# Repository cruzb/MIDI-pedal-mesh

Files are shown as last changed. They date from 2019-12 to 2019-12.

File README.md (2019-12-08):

# MIDI Pedal and Mesh
Digital music production today has a lot of limits. In an analog world a musician can slightly tweak the angle of their bow on a violin to get a different sound. The aim of the “Mesh” is to create a digital instrument with analog levels of control in package compatible with existing digital workflows.

Effects pedals are a common tool used by guitarists to modify the sound of their instrument. These devices are often designed to make one specific sound. The aim of the “Pedal” is to create a customizable audio processing device that gives users direct access to DSP hardware while maintaining the functionality and ease of use that musicians expect.

### Watch this video to see it in action
Watch the video (https://www.youtube.com/watch?v=qIbVKWIkZBc)

## Implementation
### Overview
The Mesh and Pedal work as standard audio components that can fit seamlessly into any musician’s kit. The Mesh outputs a MIDI signal which can be use to generate sound through any MIDI-capable synthesizer. The Pedal takes in analog audio and performs effects processing on it before outputting it to an amplifier or speaker for play. These devices can work in tandem, independently, or with other music devices.

How it Works Together

### Pedal
- Users create effects programs on desktop and upload to the device EEPROM via a desktop application and USB connection
- Once loaded to the pedal programs can be selected via a knob
- An LCD screen in the pedal displays the active program and up to three associated parameters for it
- Input analog audio is split into two independent signal paths and processed by the selected program on an FV-1 DSP chip
- The affected signal then runs through an analog equalizer and is blended with the clean signal before it is output.

### Mesh
- Use strain sensors to read force data on two axes via ADC
- Use ADC data to do basic 2D localization of which point in grid is most pressed and by how much
- Map that point to a pitch, pitch-bend, and velocity for MIDI
- Generate MIDI packets from these data
- Send MIDI via UART at 31250 baud

## PCB Design
Three PCBs were created for this project. One for the pedal and two for the mesh. The pedal PCB contains over 160 components that handle digital and analog signals. The mesh PCBs are simpler but took special design considerations into account. Because of the analog nature of the device all analog runs were made as short as possible and processing occurs close to the sensors to deal with noise issues.

Pedal PCB Image

## Major Compontents
### Pedal
- PIC16F15355 Microcontroller
- FV-1 Spin Semiconductor DSP Chip
- HD44780-Compatible RGB 16x2 Character LCD
- FT232 USB-UART Interface
- 24LC32A External EEPROM Chip
- MAX4910ETE Audio Switch

### Mesh
- PIC16F15376 Microcontroller
- TAL221 Load Cell
- AD620 Differential Amplifier

#### Made with Jordan Frank, Ethan Brown, Charlie Light, and Spencer Haney for University of Michigan EECS 473

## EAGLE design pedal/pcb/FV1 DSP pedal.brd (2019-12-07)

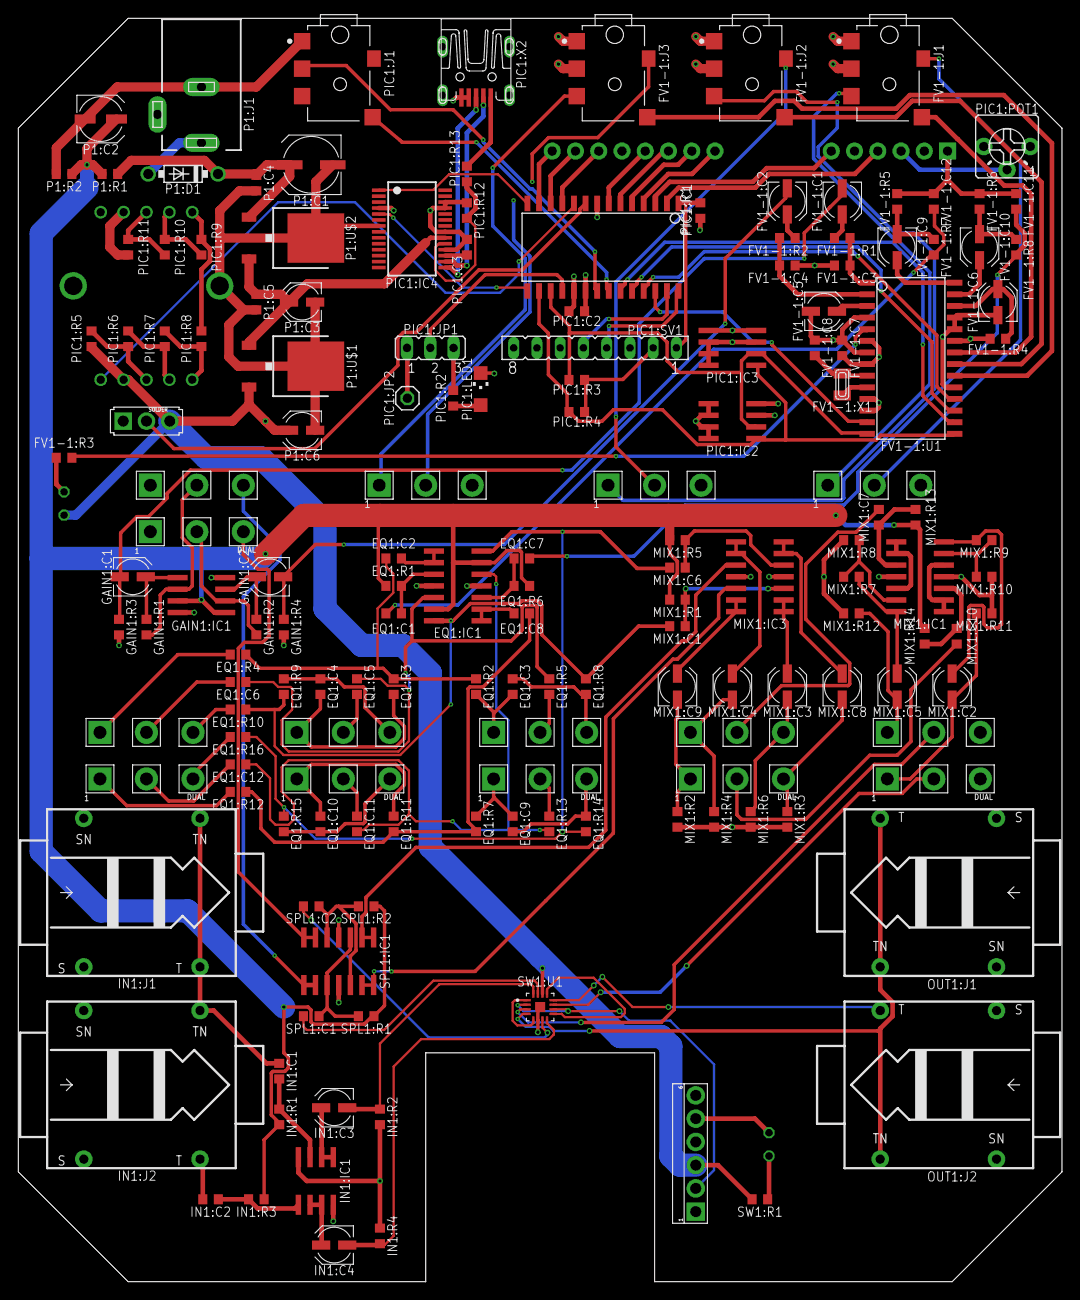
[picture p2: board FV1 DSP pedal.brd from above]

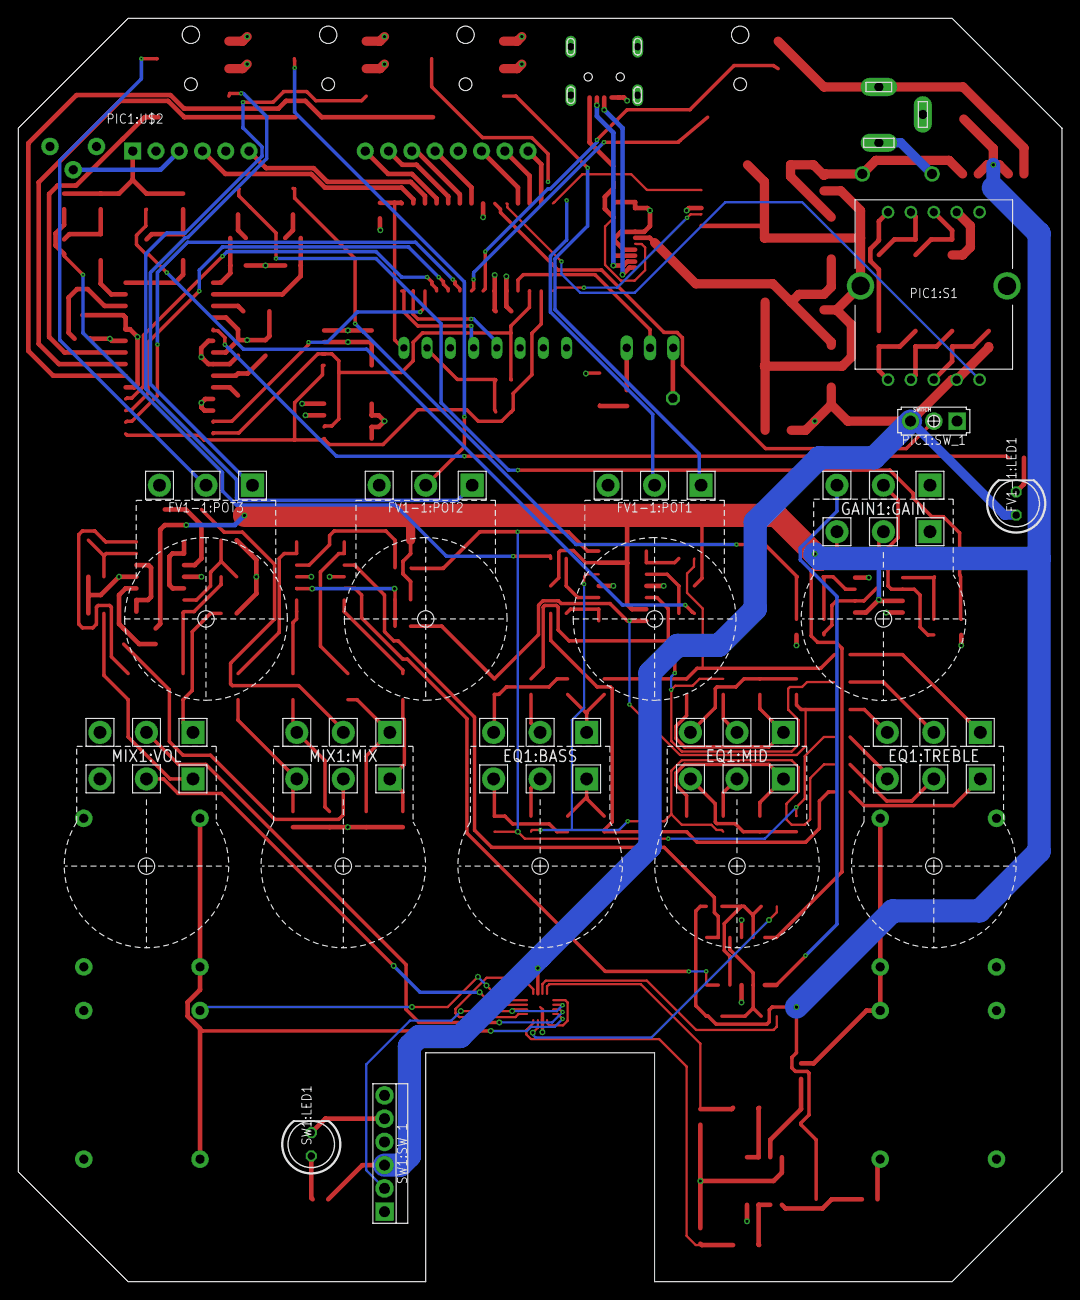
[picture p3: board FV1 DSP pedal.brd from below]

Board: 4 copper layers, 114.0 x 138.0 mm, 160 parts (4 on the bottom side), 152 nets.

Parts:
EQ1:BASS, EQ1:MID: B100k; 16MM_DUALGANG
EQ1:C1, EQ1:C7: 220n; RESISTOR_R0603
EQ1:C2, EQ1:C8: 1u; RESISTOR_R0603
EQ1:C3, EQ1:C9: 50n; RESISTOR_R0603
EQ1:C4, EQ1:C6, EQ1:C10, EQ1:C12: 5n; RESISTOR_R0603
EQ1:C5, EQ1:C11: 22n; RESISTOR_R0603
EQ1:IC1: TL074D; SO14
EQ1:R1, EQ1:R6: 1M; RESISTOR_R0603
EQ1:R2, EQ1:R5, EQ1:R7, EQ1:R8, EQ1:R13, EQ1:R14: 11k; RESISTOR_R0603
EQ1:R3, EQ1:R9, EQ1:R11, EQ1:R15: 3.6k; RESISTOR_R0603
EQ1:R4, EQ1:R10, EQ1:R12, EQ1:R16: 1.8k; RESISTOR_R0603
EQ1:TREBLE: B500k; 16MM_DUALGANG
FV1-1:C1, FV1-1:C2, FV1-1:C5, FV1-1:C6: 1u; UD-4X5,8_NICHICON
FV1-1:C3, FV1-1:C4: 1n; RESISTOR_R0603
FV1-1:C7: 100n; RESISTOR_R0603
FV1-1:C8: 15p; RESISTOR_R0603
FV1-1:C9, FV1-1:C10: 3.3u; UD-4X5,8_NICHICON
FV1-1:C11, FV1-1:C12: 2.2n; RESISTOR_R0603
FV1-1:J1, FV1-1:J2, FV1-1:J3: SJ2-25313D-SMT-TR; CUI_SJ2-25313D-SMT-TR
FV1-1:LED1: LED5MM
FV1-1:POT1, FV1-1:POT2, FV1-1:POT3: B10k; 16MM_B.MOUNT
FV1-1:R1, FV1-1:R2, FV1-1:R7, FV1-1:R8: 1k; RESISTOR_R0603
FV1-1:R3, FV1-1:R4: 100; RESISTOR_R0603
FV1-1:R5, FV1-1:R6: 10k; RESISTOR_R0603
FV1-1:U1: SO28W
FV1-1:X1: FC-135; XTAL3215
GAIN1:C1, GAIN1:C2: 10u; UD-4X5,8_NICHICON
GAIN1:GAIN: A50k; 16MM_DUALGANG
GAIN1:IC1: TL072D; SO08
GAIN1:R1: 33.3k; RESISTOR_R0603
GAIN1:R2: 33.3K; RESISTOR_R0603
GAIN1:R3, GAIN1:R4: 1M; RESISTOR_R0603
IN1:C1, IN1:C2: 220n; RESISTOR_R0603
IN1:C3, IN1:C4: 10u; UD-4X5,8_NICHICON
IN1:IC1: TL072D; SO08
IN1:J1, IN1:J2: SWITCHED_MONO_JACK; TS_SW
IN1:R1, IN1:R2, IN1:R3, IN1:R4: 1M; RESISTOR_R0603
MIX1:C1, MIX1:C6, MIX1:C7, MIX1:C10: 220n; RESISTOR_R0603
MIX1:C2, MIX1:C3, MIX1:C4, MIX1:C5, MIX1:C8, MIX1:C9: 10u; UD-4X5,8_NICHICON
MIX1:IC1, MIX1:IC3: TL074D; SO14
MIX1:MIX: B50k; 16MM_DUALGANG
MIX1:R1, MIX1:R2, MIX1:R3, MIX1:R4, MIX1:R5, MIX1:R6, MIX1:R11, MIX1:R12, MIX1:R13, MIX1:R14: 1M; RESISTOR_R0603
MIX1:R7, MIX1:R9: 200; RESISTOR_R0603
MIX1:R8, MIX1:R10: 100; RESISTOR_R0603
MIX1:VOL: A50k; 16MM_DUALGANG
OUT1:J1, OUT1:J2: SWITCHED_MONO_JACK; TS_SW
P1:C1: 47u; UD-6,3X5,8_NICHICON
P1:C2: 22u; UD-5X5,8_NICHICON
P1:C3, P1:C6: 2.2u; UD-4X5,8_NICHICON
P1:C4, P1:C5: 100n; RESISTOR_R0603
P1:D1: 1N5817-B; DO41-7.6
P1:J1: DCJ0202
P1:R1, P1:R2: 33k; RESISTOR_R0603
P1:U$1: LF33ABDT-TR; TO252
P1:U$2: LF50ABDT-TR; TO252
PIC1:C2, PIC1:C3: 100n; RESISTOR_R0603
PIC1:IC1: PIC16LF1516/18SO; SO28W
PIC1:IC2, PIC1:IC3: 24LC32ASN; SO-08
PIC1:IC4: FT232RL; SSOP28
PIC1:J1: SJ2-25313D-SMT-TR; CUI_SJ2-25313D-SMT-TR
PIC1:JP1: JP2
PIC1:JP2: 1X01
PIC1:LED1: CHIPLED_1206
PIC1:POT1: TRIM1
PIC1:R1: 50k; RESISTOR_R0603
PIC1:R2: 100; RESISTOR_R0603
PIC1:R3, PIC1:R4, PIC1:R5, PIC1:R6, PIC1:R7, PIC1:R8, PIC1:R9, PIC1:R10, PIC1:R11, PIC1:R12: 10k; RESISTOR_R0603
PIC1:R13: 4k7; RESISTOR_R0603
PIC1:S1: SR1712F-0108-20F0A-N9-N-027; SR1712F010820F0AN9N027
PIC1:SV1: FE08
PIC1:SW_1: SPDT.MINI
PIC1:U$2: LCD16X2RGB
PIC1:X2: MINI-USB-UX60-MB-5S8; UX60-MB-5S8
SPL1:C1, SPL1:C2: 220n; RESISTOR_R0603
SPL1:IC1: TL074D; SO14
SPL1:R1, SPL1:R2: 1M; RESISTOR_R0603
SW1:LED1: LED5MM
SW1:R1: 100; RESISTOR_R0603
SW1:SW_1: DPDT.WIRE
SW1:U1: MAX4910ETET; QFN50P300X300X80-17N

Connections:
3.3V: FV1-1:C7.2, FV1-1:J1.3, FV1-1:J2.3, FV1-1:J3.3, FV1-1:LED1.A, FV1-1:R4.2, FV1-1:U1.6, FV1-1:U1.8, FV1-1:U1.23, P1:C6.+, P1:U$1.2, PIC1:C2.1, PIC1:IC1.20, PIC1:IC2.8, PIC1:IC3.1, PIC1:IC3.8, PIC1:IC4.4, PIC1:POT1.3, PIC1:R1.1, PIC1:R3.2, PIC1:R4.1, PIC1:R5.1, PIC1:S1.2, PIC1:SV1.2, PIC1:SW_1.3, PIC1:U$2.2, PIC1:U$2.15, SW1:R1.1, SW1:SW_1.A3, SW1:U1.14
4.5V: EQ1:IC1.6, EQ1:IC1.13, EQ1:R1.1, EQ1:R6.1, GAIN1:IC1.3, GAIN1:IC1.5, IN1:R1.2, IN1:R3.2, MIX1:R1.2, MIX1:R5.1, MIX1:R13.2, MIX1:R14.2, P1:C2.+, P1:R1.1, P1:R2.2, SPL1:R1.2, SPL1:R2.2
9V: EQ1:IC1.4, GAIN1:IC1.8, IN1:IC1.8, MIX1:IC1.4, MIX1:IC3.4, P1:C1.+, P1:C4.1, P1:D1.C, P1:R1.2, P1:U$2.1, SPL1:IC1.4
EQ1:N$1: EQ1:C7.1, EQ1:IC1.10, EQ1:R6.2
EQ1:N$2: EQ1:C2.2, EQ1:IC1.1, EQ1:IC1.2
EQ1:N$3: EQ1:C2.1, EQ1:R2.2, EQ1:R3.2, EQ1:R4.2
EQ1:N$4: EQ1:BASS.1, EQ1:C3.2, EQ1:R2.1
EQ1:N$5: EQ1:C4.2, EQ1:MID.1, EQ1:R3.1
EQ1:N$6: EQ1:R4.1, EQ1:TREBLE.1
EQ1:N$7: EQ1:C4.1, EQ1:MID.3, EQ1:R9.2
EQ1:N$8: EQ1:R10.2, EQ1:TREBLE.3
EQ1:N$9: EQ1:C1.1, EQ1:IC1.3, EQ1:R1.2
EQ1:N$10: EQ1:BASS.3, EQ1:C3.1, EQ1:R8.2
EQ1:N$11: EQ1:C5.1, EQ1:C6.1, EQ1:IC1.5, EQ1:R5.2
EQ1:N$12: EQ1:C5.2, EQ1:MID.2
EQ1:N$13: EQ1:C6.2, EQ1:TREBLE.2
EQ1:N$14: EQ1:BASS.2, EQ1:R5.1
EQ1:N$16: EQ1:C8.2, EQ1:IC1.8, EQ1:IC1.9
EQ1:N$17: EQ1:C8.1, EQ1:R7.2, EQ1:R11.2, EQ1:R12.2
EQ1:N$18: EQ1:BASS.4, EQ1:C9.2, EQ1:R7.1
EQ1:N$19: EQ1:C10.2, EQ1:MID.4, EQ1:R11.1
EQ1:N$20: EQ1:R12.1, EQ1:TREBLE.4
EQ1:N$21: EQ1:C10.1, EQ1:MID.6, EQ1:R15.2
EQ1:N$22: EQ1:R16.2, EQ1:TREBLE.6
EQ1:N$23: EQ1:BASS.6, EQ1:C9.1, EQ1:R14.2
EQ1:N$25: EQ1:C11.1, EQ1:C12.1, EQ1:IC1.12, EQ1:R13.2
EQ1:N$26: EQ1:C11.2, EQ1:MID.5
EQ1:N$27: EQ1:C12.2, EQ1:TREBLE.5
EQ1:N$28: EQ1:BASS.5, EQ1:R13.1
FV1-1:N$1: FV1-1:J1.11, FV1-1:POT3.1
FV1-1:N$2: FV1-1:J1.10, FV1-1:POT3.2
FV1-1:N$3: FV1-1:J1.2, FV1-1:U1.22
FV1-1:N$4: FV1-1:C6.+, FV1-1:R4.1, FV1-1:U1.26
FV1-1:N$5: FV1-1:LED1.K, FV1-1:R3.1
FV1-1:N$6: FV1-1:C1.+, FV1-1:R1.1
FV1-1:N$7: FV1-1:R3.2, FV1-1:U1.5
FV1-1:N$8: FV1-1:C9.+, FV1-1:U1.28
FV1-1:N$9: FV1-1:C2.+, FV1-1:R2.1
FV1-1:N$10: FV1-1:C3.2, FV1-1:R1.2, FV1-1:U1.1
FV1-1:N$11: FV1-1:C4.2, FV1-1:R2.2, FV1-1:U1.2
FV1-1:N$12: FV1-1:C5.+, FV1-1:U1.3
FV1-1:N$13: FV1-1:C8.2, FV1-1:U1.9, FV1-1:X1.P$2
FV1-1:N$14: FV1-1:J2.10, FV1-1:POT2.2
FV1-1:N$15: FV1-1:J2.2, FV1-1:U1.21
FV1-1:N$16: FV1-1:J2.11, FV1-1:POT2.1
FV1-1:N$17: FV1-1:J3.11, FV1-1:POT1.1
FV1-1:N$18: FV1-1:J3.10, FV1-1:POT1.2
FV1-1:N$19: FV1-1:J3.2, FV1-1:U1.20
FV1-1:N$20: FV1-1:C10.+, FV1-1:U1.27
FV1-1:N$21: FV1-1:U1.10, FV1-1:X1.P$1
FV1-1:N$22: FV1-1:C9.-, FV1-1:R5.2, FV1-1:R7.1
FV1-1:N$23: FV1-1:C10.-, FV1-1:R6.2, FV1-1:R8.1
GAIN1:N$1: GAIN1:C1.+, GAIN1:IC1.1, GAIN1:R1.2
GAIN1:N$2: GAIN1:C2.+, GAIN1:IC1.7, GAIN1:R2.2
GAIN1:N$3: GAIN1:GAIN.5, GAIN1:IC1.6, GAIN1:R2.1
GAIN1:N$4: GAIN1:GAIN.2, GAIN1:IC1.2, GAIN1:R1.1
GND: EQ1:IC1.11, FV1-1:C3.1, FV1-1:C4.1, FV1-1:C5.-, FV1-1:C6.-, FV1-1:C7.1, FV1-1:C8.1, FV1-1:C11.1, FV1-1:C12.1, FV1-1:J1.1, FV1-1:J2.1, FV1-1:J3.1, FV1-1:POT1.3, FV1-1:POT2.3, FV1-1:POT3.3, FV1-1:R5.1, FV1-1:R6.1, FV1-1:U1.4, FV1-1:U1.7, FV1-1:U1.11, FV1-1:U1.12, FV1-1:U1.19, FV1-1:U1.24, FV1-1:U1.25, GAIN1:IC1.4, GAIN1:R3.1, GAIN1:R4.1, IN1:IC1.4, IN1:J1.S, IN1:J1.SN, IN1:J2.S, IN1:J2.SN, IN1:R2.1, IN1:R4.1, MIX1:IC1.11, MIX1:IC3.11, MIX1:R2.2, MIX1:R3.2, MIX1:R4.2, MIX1:R6.2, MIX1:R8.2, MIX1:R10.2, MIX1:R11.2, MIX1:R12.2, MIX1:VOL.3, MIX1:VOL.6, OUT1:J1.S, OUT1:J1.SN, OUT1:J2.S, OUT1:J2.SN, P1:C1.-, P1:C2.-, P1:C3.-, P1:C4.2, P1:C5.2, P1:C6.-, P1:J1.3, P1:R2.1, P1:U$1.3, P1:U$2.3, PIC1:C2.2, PIC1:C3.2, PIC1:IC1.8, PIC1:IC1.19, PIC1:IC2.1, PIC1:IC2.2, PIC1:IC2.3, PIC1:IC2.4, PIC1:IC2.7, PIC1:IC3.2, PIC1:IC3.3, PIC1:IC3.4, PIC1:IC3.7, PIC1:IC4.7, PIC1:IC4.18, PIC1:IC4.21, PIC1:IC4.25, PIC1:IC4.26, PIC1:J1.1, PIC1:LED1.C, PIC1:POT1.1, PIC1:R11.2, PIC1:R12.2, PIC1:S1.9, PIC1:S1.MH1, PIC1:S1.MH2, PIC1:SV1.3, PIC1:SW_1.1, PIC1:U$2.1, PIC1:U$2.5, PIC1:X2.4, PIC1:X2.5, SPL1:IC1.11, SW1:SW_1.A1, SW1:SW_1.B3, SW1:U1.6, SW1:U1.17
IN1:N$1: IN1:C1.2, IN1:J1.T, IN1:J1.TN, IN1:J2.TN
IN1:N$3: IN1:C3.+, IN1:IC1.1, IN1:IC1.2
IN1:N$5: IN1:C2.1, IN1:IC1.5, IN1:R3.1
IN1:N$6: IN1:C1.1, IN1:IC1.3, IN1:R1.1
IN1:N$7: IN1:C4.+, IN1:IC1.6, IN1:IC1.7
IN1:N$8: IN1:C2.2, IN1:J2.T
MIX1:N$1: MIX1:C4.-, MIX1:MIX.1, MIX1:R4.1
MIX1:N$2: MIX1:IC1.8, MIX1:IC1.9, MIX1:IC1.12
MIX1:N$3: MIX1:IC1.13, MIX1:R9.1, MIX1:R10.1
MIX1:N$4: MIX1:C2.+, MIX1:IC1.14, MIX1:R9.2
MIX1:N$5: MIX1:C3.-, MIX1:MIX.3, MIX1:R6.1
MIX1:N$6: MIX1:C7.1, MIX1:IC1.3, MIX1:R13.1
MIX1:N$7: MIX1:C4.+, MIX1:IC3.1, MIX1:IC3.2
MIX1:N$8: MIX1:C3.+, MIX1:IC3.8, MIX1:IC3.9
MIX1:N$9: MIX1:C10.1, MIX1:IC1.10, MIX1:R14.1
MIX1:N$10: MIX1:C10.2, MIX1:MIX.5
MIX1:N$11: MIX1:C7.2, MIX1:MIX.2
MIX1:N$13: MIX1:C9.-, MIX1:MIX.4, MIX1:R2.1
MIX1:N$14: MIX1:C6.1, MIX1:IC3.12, MIX1:R5.2
MIX1:N$15: MIX1:C1.1, MIX1:IC3.10, MIX1:R1.1
MIX1:N$18: MIX1:C9.+, MIX1:IC3.6, MIX1:IC3.7
MIX1:N$19: MIX1:IC1.1, MIX1:IC1.2, MIX1:IC1.5
MIX1:N$20: MIX1:C8.-, MIX1:MIX.6, MIX1:R3.1
MIX1:N$21: MIX1:C8.+, MIX1:IC3.13, MIX1:IC3.14
MIX1:N$22: MIX1:IC1.6, MIX1:R7.1, MIX1:R8.1
MIX1:N$23: MIX1:C5.+, MIX1:IC1.7, MIX1:R7.2
MIX1:N$25: MIX1:C2.-, MIX1:R11.1, MIX1:VOL.4
MIX1:N$28: MIX1:C5.-, MIX1:R12.1, MIX1:VOL.1
unnamed: MIX1:IC3.3, SPL1:IC1.8, SPL1:IC1.9
unnamed: MIX1:IC3.5, SPL1:IC1.6, SPL1:IC1.7
unnamed: EQ1:IC1.7, EQ1:R8.1, EQ1:R9.1, EQ1:R10.1, MIX1:C1.2
unnamed: EQ1:IC1.14, EQ1:R14.1, EQ1:R15.1, EQ1:R16.1, MIX1:C6.2
unnamed: GAIN1:GAIN.6, SPL1:IC1.13, SPL1:IC1.14
unnamed: GAIN1:GAIN.3, SPL1:IC1.1, SPL1:IC1.2
unnamed: IN1:C3.-, IN1:R2.2, SW1:U1.16
unnamed: FV1-1:C1.-, GAIN1:C1.-, GAIN1:R3.2
unnamed: FV1-1:C2.-, GAIN1:C2.-, GAIN1:R4.2
unnamed: EQ1:C1.2, FV1-1:C12.2, FV1-1:R7.2
unnamed: EQ1:C7.2, FV1-1:C11.2, FV1-1:R8.2
unnamed: IN1:C4.-, IN1:R4.2, SW1:U1.8
unnamed: OUT1:J1.T, OUT1:J1.TN, OUT1:J2.TN, SW1:U1.4
unnamed: OUT1:J2.T, SW1:U1.12
unnamed: P1:C3.+, P1:C5.1, P1:U$1.1, P1:U$2.2, PIC1:IC4.20
unnamed: SPL1:C1.2, SW1:U1.15
unnamed: SPL1:C2.2, SW1:U1.7
unnamed: MIX1:VOL.5, SW1:U1.11
unnamed: MIX1:VOL.2, SW1:U1.3
unnamed: FV1-1:U1.13, PIC1:IC1.26
unnamed: FV1-1:U1.18, PIC1:IC1.25
unnamed: FV1-1:U1.17, PIC1:IC1.24
unnamed: FV1-1:U1.16, PIC1:IC1.23
unnamed: FV1-1:U1.14, PIC1:IC1.17, PIC1:IC2.6, PIC1:IC3.6, PIC1:R3.1
unnamed: FV1-1:U1.15, PIC1:IC1.16, PIC1:IC2.5, PIC1:IC3.5, PIC1:R4.2
P1:N$27: P1:D1.A, P1:J1.1
PIC1:!MCLR: PIC1:IC1.1, PIC1:R1.2, PIC1:SV1.1
PIC1:ICSPCLK: PIC1:IC1.27, PIC1:SV1.5
PIC1:ICSPDAT: PIC1:IC1.28, PIC1:SV1.4
PIC1:INT_EXT: PIC1:IC1.9, PIC1:SW_1.2
PIC1:LCD_D4: PIC1:IC1.4, PIC1:U$2.11
PIC1:LCD_D5: PIC1:IC1.5, PIC1:U$2.12
PIC1:LCD_D6: PIC1:IC1.6, PIC1:U$2.13
PIC1:LCD_D7: PIC1:IC1.7, PIC1:U$2.14
PIC1:LCD_EN: PIC1:IC1.3, PIC1:U$2.6
PIC1:LCD_RS: PIC1:IC1.2, PIC1:U$2.4
PIC1:MIDI_RX: PIC1:IC1.22, PIC1:J1.2
PIC1:MIDI_TX: PIC1:IC1.21, PIC1:J1.3
PIC1:N$1: PIC1:IC1.18, PIC1:JP1.2
PIC1:N$2: PIC1:JP1.1, PIC1:JP2.1
PIC1:N$3: PIC1:C3.1, PIC1:IC4.17
PIC1:N$4: PIC1:IC4.19, PIC1:R12.1, PIC1:R13.2
PIC1:N$5: PIC1:JP1.3, PIC1:R2.2
PIC1:N$6: PIC1:LED1.A, PIC1:R2.1
PIC1:N$7: PIC1:R13.1, PIC1:X2.1
PIC1:N$9: PIC1:R5.2, PIC1:R6.1, PIC1:S1.3
PIC1:N$10: PIC1:R6.2, PIC1:R7.1, PIC1:S1.4
PIC1:N$11: PIC1:R7.2, PIC1:R8.1, PIC1:S1.5
PIC1:N$12: PIC1:R8.2, PIC1:R9.1, PIC1:S1.6
PIC1:N$13: PIC1:R9.2, PIC1:R10.1, PIC1:S1.7
PIC1:N$14: PIC1:R10.2, PIC1:R11.1, PIC1:S1.8
PIC1:N$16: PIC1:POT1.2, PIC1:U$2.3
PIC1:PWM3: PIC1:IC1.11, PIC1:U$2.16
PIC1:PWM4: PIC1:IC1.12, PIC1:U$2.17
PIC1:PWM5: PIC1:IC1.13, PIC1:U$2.18
PIC1:P_SEL: PIC1:IC1.10, PIC1:S1.1
PIC1:USB_DM: PIC1:IC4.16, PIC1:X2.2
PIC1:USB_DP: PIC1:IC4.15, PIC1:X2.3
PIC1:USB_RX: PIC1:IC1.14, PIC1:IC4.1
PIC1:USB_TX: PIC1:IC1.15, PIC1:IC4.5
SPL1:N$3: SPL1:C2.1, SPL1:IC1.5, SPL1:IC1.12, SPL1:R2.1
SPL1:N$5: SPL1:C1.1, SPL1:IC1.3, SPL1:IC1.10, SPL1:R1.1
SW1:CB: SW1:SW_1.A2, SW1:U1.2, SW1:U1.10
SW1:N$1: SW1:LED1.K, SW1:SW_1.B2
SW1:N$5: SW1:LED1.A, SW1:R1.2
SW1:NC_12: SW1:U1.1, SW1:U1.5
SW1:NC_34: SW1:U1.9, SW1:U1.13

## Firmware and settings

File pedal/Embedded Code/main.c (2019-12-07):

#include "mcc_generated_files/mcc.h"
#include "eeprom.h"
#include "desktop_interface.h"
#include "lcd.h"
#include "fv1.h"
#include <stdint.h>
#include <stdlib.h>

uint8_t getProgram(uint16_t adc_val);

void main(void) {
    // initialize the device
    SYSTEM_Initialize();
    INTERRUPT_GlobalInterruptEnable();
    INTERRUPT_PeripheralInterruptEnable();

    GPIO_SetLow();
    

    //Initialize data eeprom with internal program descriptions
    char * internalDescriptions[8] = {
        "Chorus-Reverb   RmixCratCmix",
        "Flange-Reverb   RmixFratFmix",
        "Trem-Reverb     RmixTratTmix",
        "Pitch Shift     Shft --  -- ",
        "Pitch Echo      ShftTime Mix",
        "TEST             --  --  -- ",
        "Reverb 1        Time HF  LF ",
        "Reverb 2        Time HF  LF "
    };



    /*for (uint8_t i = 0; i < 8; i++) {
        EEPROMwrite(DATA_EEPROM, DATA_ADDR[i], (uint8_t*) internalDescriptions[i], 28);
    }*/


    LCDInit();
    //LCDClear();
    LCDSetBacklight(0, 0, 255);

    //Handle different tasks stuff
#define     IDLE    0x0
#define     USB     0x1 
#define     MIDI    0x2
#define     LCD     0x3

    uint8_t state = LCD;
    uint8_t int_ext = INT_EXT_GetValue();
    uint8_t program = getProgram(ADC_GetConversion(PGM_SELECT) >> 6);


    //Program Select/LCD stuff
    uint8_t LCDbuf[28];

    //USB UART Stuff
    uint8_t USBbuf[64]; //64 byte message

    /* MESSAGES
     *
     * 1: 1 byte location + 16 byte name + 3*4 byte pot names
     * 2: program data 0 - 63
     * 3: program data 64 - 127
     * 4: program data 128 - 191
     * 5: program data 192 - 255
     * 6: program data 256 - 319
     * 7: program data 320 - 383
     * 8: program data 384 - 447
     * 9: program data 448 - 511
     *
     */

    uint8_t i = 0;

    while (1) {

        __delay_ms(100);
        if (i) {
            //GPIO_SetHigh();
        } else {
            //GPIO_SetLow();
        }
        i = (i + 1) % 2;


        switch (state) {

            case USB:
                                
                confirmTransaction();          
                
                uint8_t location;
                while (1) {
                    if (USBgetHeader(USBbuf)) {
                        location = USBbuf[0];
                        EEPROMwrite(DATA_EEPROM, DATA_ADDR[location + 8], USBbuf + 1, 28);
                        confirmTransaction();
                        break;
                    } else {
                        denyTransaction();
                    }
                }
                
                for (uint8_t i = 0; i < 8; i++) {
                    while (1) {
                        if (USBgetProgChunk(USBbuf)) {
                            EEPROMwrite(PROG_EEPROM, PROG_ADDR[location] + (32 * (2 * i)), USBbuf, 32);
                            EEPROMwrite(PROG_EEPROM, PROG_ADDR[location] + (32 * (2 * i + 1)), USBbuf + 32, 32);
                            confirmTransaction();
                            break;
                        } else {
                            denyTransaction();
                        }
                    }
                }
                
                state = LCD;
                break;
            case MIDI:


                state = LCD;
                break;
            case LCD:

                //patch changed, get description data
                EEPROMread(DATA_EEPROM, DATA_ADDR[program + 8 * int_ext], LCDbuf, 28);
                LCDMoveCursor(0, 0);
                for (uint8_t i = 0; i < 16; i++) {
                    LCDWriteChar(LCDbuf[i]);
                }
                LCDMoveCursor(1, 0);
                for (uint8_t i = 0; i < 4; i++) {
                    LCDWriteChar(LCDbuf[i + 24]);
                }
                LCDWriteChar(' ');
                LCDWriteChar(' ');
                for (uint8_t i = 0; i < 4; i++) {
                    LCDWriteChar(LCDbuf[i + 20]);
                }
                LCDWriteChar(' ');
                LCDWriteChar(' ');
                for (uint8_t i = 0; i < 4; i++) {
                    LCDWriteChar(LCDbuf[i + 16]);
                }

                //__delay_ms(50);

                //Tell the FV-1 to switch programs
                setSource(int_ext);
                setPatch(program);

                state = IDLE;
                break;
            case IDLE:
            default:

                if (USBincomingMessage()) {
                    state = USB;
                    break;
                }

                uint8_t program_input = getProgram(ADC_GetConversion(PGM_SELECT) >> 6);
                uint8_t int_ext_input = INT_EXT_GetValue();

                if (program_input != program || int_ext_input != int_ext) {

                    program = program_input;
                    int_ext = int_ext_input;

                    state = LCD;
                    break;
                }

                //if (incoming MIDI) {
                //    state = MIDI;
                //    break;
                //}

        }
    }
}

uint8_t getProgram(uint16_t adc_val) {

    //10 bit range is 0 to 1023
    if (adc_val < 128) {
        return 7;
    } else if (adc_val < 256) {
        return 6;
    } else if (adc_val < 384) {
        return 5;
    } else if (adc_val < 512) {
        return 4;
    } else if (adc_val < 640) {
        return 3;
    } else if (adc_val < 768) {
        return 2;
    } else if (adc_val < 896) {
        return 1;
    } else if (adc_val < 1024) {
        return 0;
    }

    return 0;
}

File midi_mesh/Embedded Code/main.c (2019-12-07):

/**
  Generated Main Source File

  Company:
    Microchip Technology Inc.

  File Name:
    main.c

  Summary:
    This is the main file generated using PIC10 / PIC12 / PIC16 / PIC18 MCUs

  Description:
    This header file provides implementations for driver APIs for all modules selected in the GUI.
    Generation Information :
        Product Revision  :  PIC10 / PIC12 / PIC16 / PIC18 MCUs - 1.78
        Device            :  PIC16F15376
        Driver Version    :  2.00
*/

/*
    (c) 2018 Microchip Technology Inc. and its subsidiaries. 
    
    Subject to your compliance with these terms, you may use Microchip software and any 
    derivatives exclusively with Microchip products. It is your responsibility to comply with third party 
    license terms applicable to your use of third party software (including open source software) that 
    may accompany Microchip software.
    
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
    IN NO EVENT WILL MICROCHIP BE LIABLE FOR ANY INDIRECT, SPECIAL, PUNITIVE, 
    INCIDENTAL OR CONSEQUENTIAL LOSS, DAMAGE, COST OR EXPENSE OF ANY KIND 
    WHATSOEVER RELATED TO THE SOFTWARE, HOWEVER CAUSED, EVEN IF MICROCHIP 
    HAS BEEN ADVISED OF THE POSSIBILITY OR THE DAMAGES ARE FORESEEABLE. TO 
    THE FULLEST EXTENT ALLOWED BY LAW, MICROCHIP'S TOTAL LIABILITY ON ALL 
    CLAIMS IN ANY WAY RELATED TO THIS SOFTWARE WILL NOT EXCEED THE AMOUNT 
    OF FEES, IF ANY, THAT YOU HAVE PAID DIRECTLY TO MICROCHIP FOR THIS 
    SOFTWARE.
*/

#include "mcc_generated_files/mcc.h"
#include "mesh_discrete.h"
#include "mesh_continuous.h"


void main(void)
{
    // initialize the device
    SYSTEM_Initialize();


    INTERRUPT_GlobalInterruptEnable();
    INTERRUPT_PeripheralInterruptEnable();

    while (1)
    {
        if(PORTCbits.RC1)
			discrete();
		else 
			continuous();
        
    }
}

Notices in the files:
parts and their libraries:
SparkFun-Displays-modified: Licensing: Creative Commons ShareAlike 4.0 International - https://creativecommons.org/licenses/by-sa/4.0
